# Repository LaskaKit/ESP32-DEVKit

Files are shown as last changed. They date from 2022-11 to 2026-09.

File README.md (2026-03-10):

# ESP32 

DEVkit Are you looking for a combination of a very economical development kit with ESP32 with absolutely simple programming? We have prepared a new development kit just for you, which combines very low power consumption and an integrated programmer. By selecting the right components, the power consumption of the [ESP32-DEVkit](https://www.laskakit.cz/laskakit-esp32-devkit/) in the ESP32's deepest sleep is only 9.5 uA. 

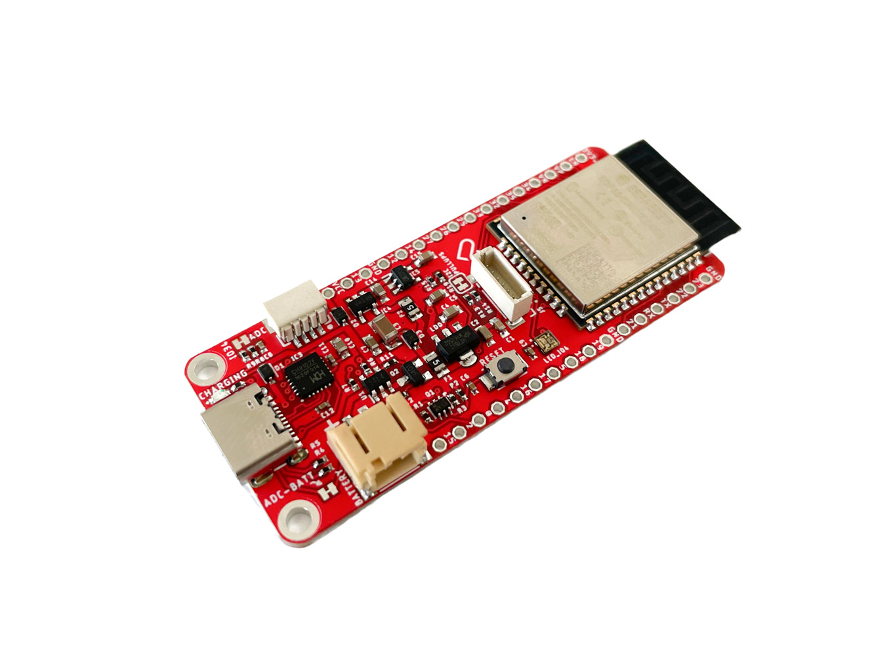
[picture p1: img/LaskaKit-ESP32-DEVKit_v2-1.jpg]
ESP32-DEVkit


As you can see in the picture above, the LaskaKit ESP32 DEVkit comes equipped with a USB-C connector for battery charging and programming, a JST-PH-2 connector for a LiPo/LiIon battery, a user-programmable button, a RESET button, and GPIO headers on each side of the board. 

What we are 100% sure of is that you will like our connector, which we have dubbed "μŠup". 

It's small and durable at the same time and you can't switch the polarity of the sensor by mistake. It's just a safe and reliable method of connecting sensors or I/O devices. With this connector, you can connect the development board to whole host of devices. The connector is pin-compatible with Adafruit Stemma and Sparkfun Qwiik. Some examples of sensors we've designed are: [SHT40 (temperature/humidity)](https://www.laskakit.cz/laskakit-sht40-senzor-teploty-a-vlhkosti-vzduchu/), [BME280 (temperature, humidity, atmospheric pressure)](https://www.laskakit.cz/arduino-senzor-tlaku--teploty-a-vlhkosti-bme280/), [SCD41 (CO2, temperature, humidity)](https://www.laskakit.cz/laskakit-scd41-senzor-co2--teploty-a-vlhkosti-vzduchu/).

The ESP32-DEVkit contains a voltage divider that is connected to the IO34 (a solder bridge on the back of the board must be shorted to enable it). 

## Charging circuitry

Battery charging is enabled by the TP4054 charging circuit, while a stable voltage of 3.3V for the microcontroller is provided by the RT9080-33 low-power voltage stabilizer. The CH9102F USB-UART converter allows easy programming and communication with a computer. 

## Other hardware 

Outside of what we have already mentioned, there is also a user-programmable button, reset button, and RGB LED (SK6812) on the board for signaling or user interface. The pin pitch is designed so that the board can be easily inserted into the solderless contact field, making prototyping and development much easier. 

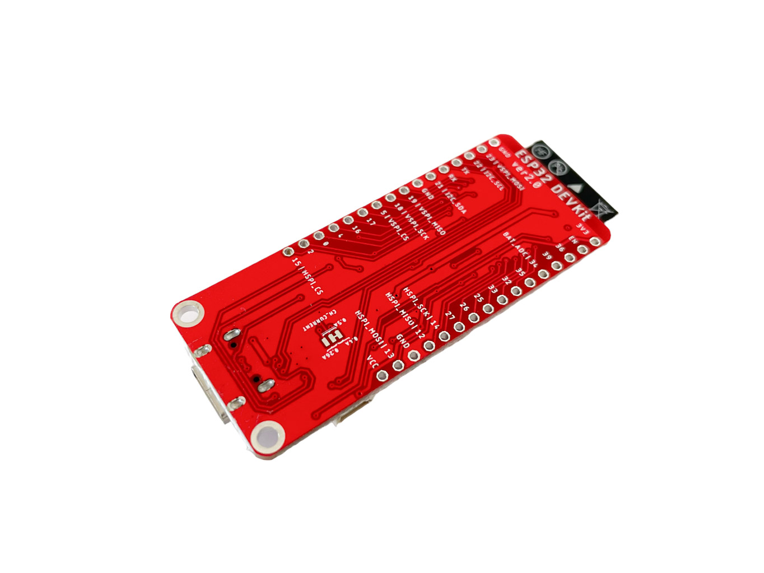
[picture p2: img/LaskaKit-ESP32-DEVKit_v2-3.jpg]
ESP32-DEVkit


## Power consumption 

The power consumption of the ESP32 DevKit during deep-sleep mode is only 12,7 µA (at 4.2V). This means that the entire board, powered only by a Li-ion battery with a programmer, consumes only 12,7 µA.

## Programming
Programming is trivial thanks to the CH9102F programmer. All you have to do is connect a USB-C cable to the board, select the correct port in Arduino IDE, and press "Upload".

Example programs can be found at: https://github.com/LaskaKit/ESP32-DEVKit/tree/main/SW

## Specifications

- Microcontroller: ESP32-WROOM-32 (16 MB Flash)
- Wireless connectivity: Wi-Fi 802.11 b/g/n, Bluetooth
- Power: USB-C, 5V, or 1S LiIon/LiPol battery
- Vin: 3,5–5,5 V
- Battery charging: Integrated TP4054 charging circuit
- Voltage regulators:
  - ESP32:  RT9080
  - Connected devices: RT9080, IO2 -> HIGH to enable
- USB-UART converter: CH9102F
- Deep sleep power consuption: ~12,7 µA (without peripherals)
- Device buses:
  - µŠup I2C: JST-SH 4 pin (SDA: IO21; SCL: IO22)
  - µŠup SPI: JST-SH 6 pin (CS: IO15; MOSI: IO13; SCK: IO14; MISO: IO12)
- LED: SK6812-EC20 (adressable RGB LED at IO4)
- Button: IO17 -> Pressed = LOW
- Battery connector: JST-PH 2-pin
- External antenna connector (IPEX version): IPEX1
- Pin spacing: compatible with solderless breadboards and prototype boards
- Dimensions: 65,5 × 25,5 × 7,5 mm
- Mass: ~9 g

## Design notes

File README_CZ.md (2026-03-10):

# ESP32 DEVkit
Hledáš kombinaci velmi úsporného vývojového kitu s ESP32 s naprosto jednoduchým programováním? Právě pro tebe jsme připravili nový vývojový kit, který práce kombinuje velmi nízkou spotřebu a integrovaný programátor. Díky výběru vhodných součátek je spotřeba [ESP32-DEVkit](https://www.laskakit.cz/laskakit-esp32-devkit/) v nejhlubším spánku ESP32 pouhých 9.5 uA. 

ESP32-DEVkit

Jak můžeš vidět na obrázku výše, vývojový kit ESO32 DEVkit obsahuje USB-C konektor pro nabíjení akumulátoru a programování, konektor pro Lipol akumulátor, uživatelské tlačitko, tlačítko RESET, a GPIO hřebínky po obou stranách desky. 

Co jsme si 100% jistí je, že se ti zalíbí náš konektor, který jsme nazvali μŠup. Je to malý, zároveň odolný a nemůže se ti stát, že bys čidlo přepóloval. Je prostě bezpečný. S tímto konektorem můžeš vývojovou desku připojit k další spoustě čidel a desek. Některé už máme skladem, na jiných pracujeme. Konektor je pinově kompatibilní s Adafruit Stemma a Sparkfun Qwiik.

Například [SHT40 (teplota/vlhkost)](https://www.laskakit.cz/laskakit-sht40-senzor-teploty-a-vlhkosti-vzduchu/), [BME280 (teplota, vlhkost, atmosférický tlak)](https://www.laskakit.cz/arduino-senzor-tlaku--teploty-a-vlhkosti-bme280/), [SCD41 (CO2, teplota, vlhkost)](https://www.laskakit.cz/laskakit-scd41-senzor-co2--teploty-a-vlhkosti-vzduchu/).

ESP32-DEVkit obsahuje dělič napětí, který je připojen k IO34 (je třeba zkratovat pájecí můstek na zadní straně desky).

## Nabíjecí obvod
Nabíjení baterie zajišťuje nabíjecí obvod TP4054, zatímco stabilní napětí 3,3 V pro mikrokontroler poskytuje nízkopříkonový stabilizátor RT9080-33. USB-UART převodník CH9102F umožňuje snadné programování a komunikaci s počítačem. 

## Další hardware
Na desce je také uživatelské tlačítko, reset tlačítko a RGB LED (SK6812) pro signalizaci nebo uživatelské rozhraní. Rozteč pinů je navržena tak, aby bylo možné desku snadno zasunout do nepájivého kontaktního pole, což výrazně usnadňuje prototypování a vývoj.

ESP32-DEVkit

## Spotřeba
Spotřeba ESP32 LP kit během režimu spánku je pouhých 12,7 µA (při 4,2V). To znamená, že celá deska, napájena pouze z Li-ion akumulátoru s osazeným programátorem odebírá pouhých 12,7 µA. 

## Programování
Programování je díky osazenému programátoru velmi jednoduché, připojíš USB-C kabel do desky, v Arduino IDE vybereš port, kam je programátor připojený a tvůj kód nahraješ kliknutím na “Nahrát”.

Vzorový kód nalezneš na https://github.com/LaskaKit/ESP32-DEVKit/tree/main/SW

## Specifikace

- Mikrokontroler: ESP32-WROOM-32 (16 MB Flash)
- Bezdrátová konektivita: Wi-Fi 802.11 b/g/n, Bluetooth
- Napájení: přes USB-C nebo Li-Ion akumulátor (1 článek)
- Napájecí napětí: 3,5–5,5 V
- Nabíjení baterie: integrovaná Li-Ion nabíječka TP4054
- Stabilizátory napětí:
  - ESP:  RT9080
  - Pereferie: RT9080, IO2 -> HIGH pro zapnutí
- USB-UART převodník: CH9102F
- Odběr proudu v deep-sleep režimu: přibližně 12,7 µA (bez připojených periferií)
- Sběrnice senzorů:
  - µŠup I2C: JST-SH 4 pin (SDA: IO21; SCL: IO22)
  - µŠup SPI: JST-SH 6 pin (CS: IO15; MOSI: IO13; SCK: IO14; MISO: IO12)
- LED: SK6812-EC20 (adresovatelná RGB LED na IO4)
- Tlačítko: IO17 -> Stisknuto = LOW
- Konektor pro baterii: JST-PH 2-pin
- Konektor pro externí anténu (u IPEX verze): IPEX1
- Rozteč pinů: kompatibilní s nepájivým kontaktním polem
- Rozměry: 65,5 × 25,5 × 7,5 mm
- Hmotnost: přibližně 9 g

ESP32-DEVkit si můžeš zakoupit na https://www.laskakit.cz/laskakit-esp32-devkit/?variantId=11481

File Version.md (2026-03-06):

### Version 3.0
- All new power part
#### Version 2.0
- New µŠUP SPI connector (need to be powered by pin IO02)
- RGB LED on pin IO04 (need to be powered by pin IO02)
#### Version 1.2
- Separated LDO with Enable pin IO02 for uSup connector, 500mA max on 3.3V
#### Version 1.1
- Přidána propojka na odpojení rezistorového děliče ADC od baterie
#### Version 1.0
- Initial | Počáteční

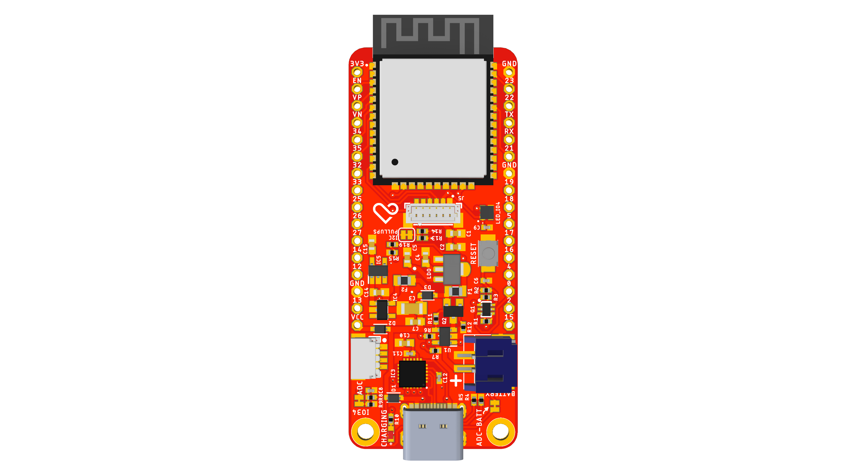
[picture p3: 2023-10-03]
img/ESP32-DEVKit_v2_front.png

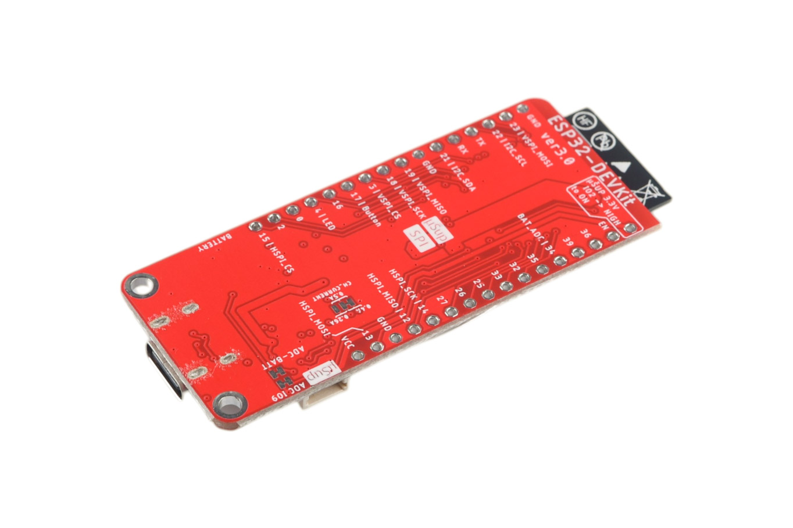
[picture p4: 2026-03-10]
img/LaskaKit-laskakit-esp32-devkit_V3-4.jpg

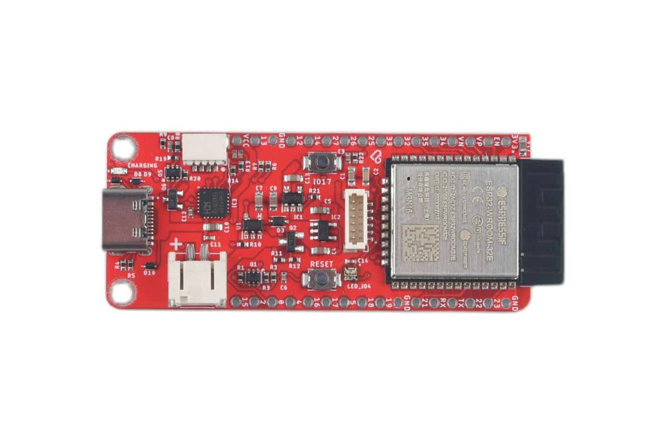
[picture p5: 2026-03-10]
img/LaskaKit-laskakit-esp32-devkit_V3-3.jpg

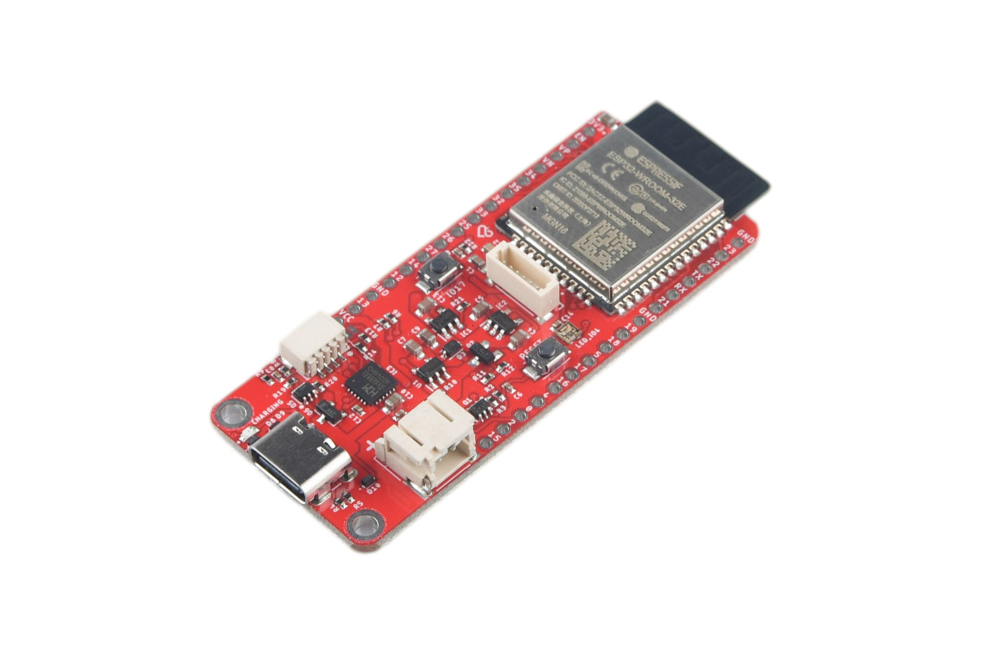
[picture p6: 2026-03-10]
img/LaskaKit-laskakit-esp32-devkit_V3-1.jpg

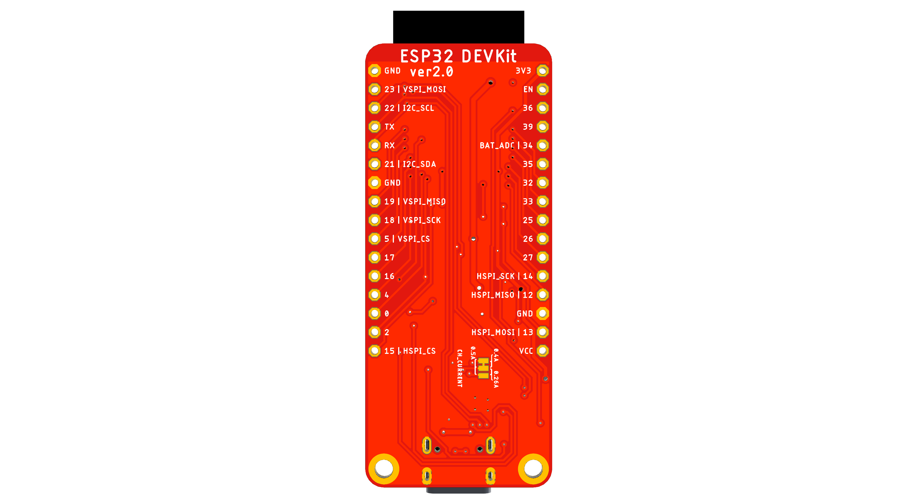
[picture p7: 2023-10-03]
img/ESP32-DEVKit_v2_back.png

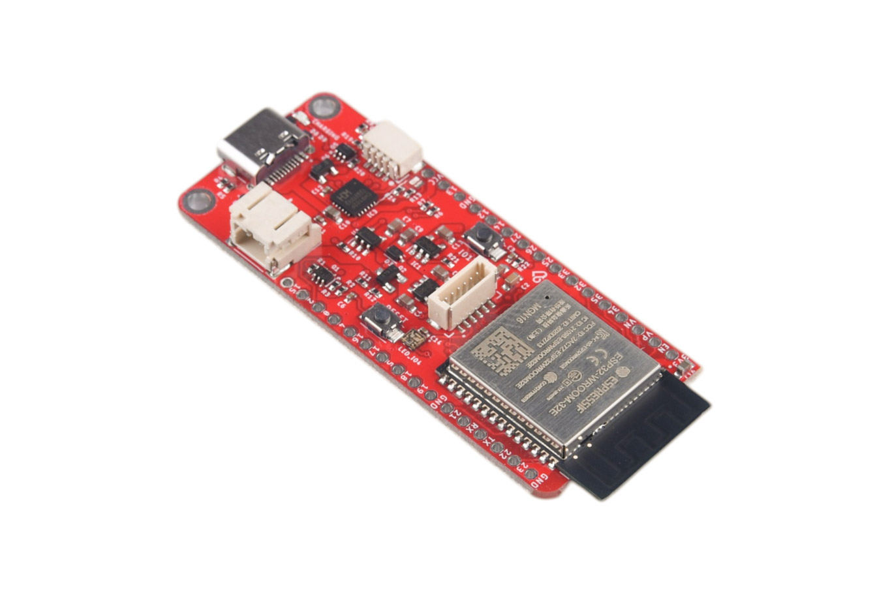
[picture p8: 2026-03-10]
img/LaskaKit-laskakit-esp32-devkit_V3-2.jpg

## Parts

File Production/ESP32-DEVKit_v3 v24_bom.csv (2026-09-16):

Comment | Designator | Footprint | LCSC Part #
1.3M | R9 | R0402
1M | R8 | R0402
1k65 | R6 | R0402
3.3k | R10 | R0402
3k3 | R7 | R0402
4.7k | R13 R14 | R0402
5.1k | R4 R5 | R0402
10k | R1 R2 R3 R11 R21 R22 | R0402
10uF/16V | C4 C5 C7 C9 C13 | C0603
22uF | C10 C16 | C0603
47k | R19 R20 | R0402
47uF | C2 | C0603
100k | R12 | R0402
100n | C11 C12 | C0402
100nF | C1 | C0603
100nF | C3 C6 C8 C14 | C0402
AO3401 | Q2 | SOT23
BAT60B | D3 | SOD323-R
CH9102F | IC3 | QFN24-4X4
DMG2305UX | Q6 | MICRO3 | C144153
EN button | RESET | TS1088R02026 | C455280
ESP32-WROOM-32E | IC4 | ESP32WROOM32E
JST-PH-2_SMD/90SMD | BATTERY | S2B-PH-SM4 | C47647
LESD5D5.0CT1G | D8 D9 D10 | LESD5D50CT1G
MMDT3904 | Q1 | SC70-6 | C268586
MMDT5401 | Q5 | SC70-6 | C54540
RED | CHARGING | CHIP-LED0603 | C2286
RT9080-33GJ5 | IC1 IC2 | SOT94P280X100-5N
SK6812-EC20 | LED_IO4 | SK6812EC20
TP4054 | U1 | SOT-23-5 | C32574
USB-C_GT-USB-7010B | J4 | G-SWITCH_GT-USB-7010B | C2837092
USUP_4P_V | J3 | 1X04_1MM_RA
USUP_SPI_CONNECTOR_VERT | J5 | 1X06_1MM_RA_VERT | C145963
user button | IO17 | TS1088R02026 | C455280

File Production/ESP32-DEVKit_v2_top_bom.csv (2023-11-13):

Comment | Designator | Footprint | LCSC Part #
1.3M | R9 | R0402
1M | R8 R15 | R0402
1k65 | R6 | R0402
1uF | C7 | C0603
3k3 | R7 | R0402
4.7k | R13 R14 | R0402
5.1k | R4 R5 | R0402
10k | R1 R2 R3 R11 R19 | R0402
22uF | C4 C5 C10 C14 C15 | C0603
47uF | C2 | C0603
100k | R12 | R0402
100n | C11 C12 | C0402
100nF | C1 | C0603
100nF | C6 C8 C9 | C0402
100uF | C3 | C1206
330 | R10 | R0402
AO3401 | Q2 | SOT23
AP2191WG-7 | IC4 | SOT25 | C141321
BAT60B | D1 D2 D3 | SOD323-R
CH9102F | IC3 | QFN24-4X4
EN button | RESET | TS1088R02026 | C455280
ESP32-WROOM-32E | IC2 | ESP32WROOM32E
HT7833 | LDO | SOT89-BCE
JST-PH-2/90SMD | BATTERY | S2B-PH-SM4 | C47647
ME6211C33M5G | IC5 | SOT23-5
MMDT3904 | Q1 | SC70-6 | C268586
POLIFUSE0500805L | F1 F2 | 0805L | C66452
RED | CHARGING | CHIP-LED0603 | C2286
SK6812-EC20 | LED_IO4 | SK6812EC20
TP4054 | U1 | SOT-23-5 | C32574
USB-C_2-16PIN | J4 | USBC_USB-C-16P-5 | C2837092
USUP_SPI_CONNECTOR_VERT | J5 | 1X06_1MM_RA_VERT | C145963
JST-SH-4P | J3 | JST-SH-4P | C145956

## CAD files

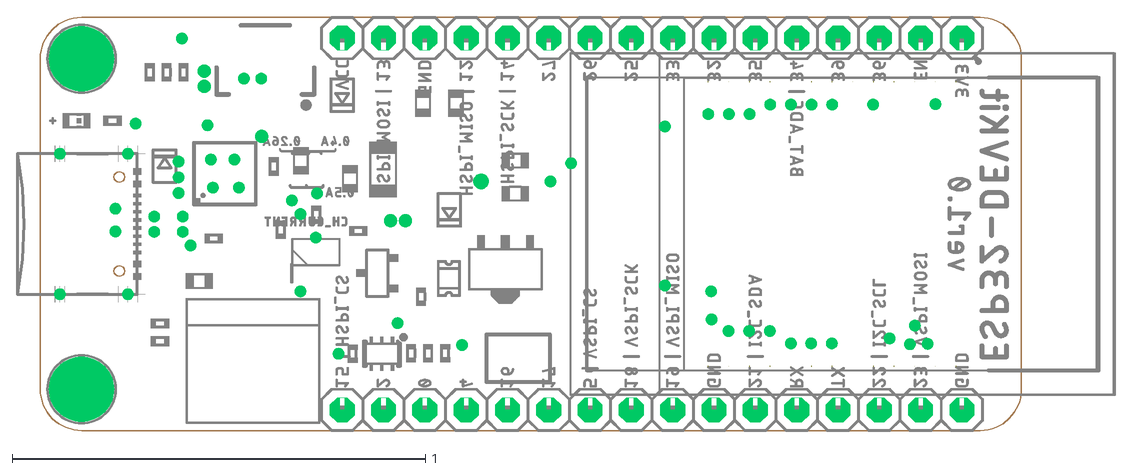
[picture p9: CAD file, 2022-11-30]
HW/ESP32-DEVKit.dxf
2.66 x 1.01

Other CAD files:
3D/ESP32-DEVKit_v3.f3d

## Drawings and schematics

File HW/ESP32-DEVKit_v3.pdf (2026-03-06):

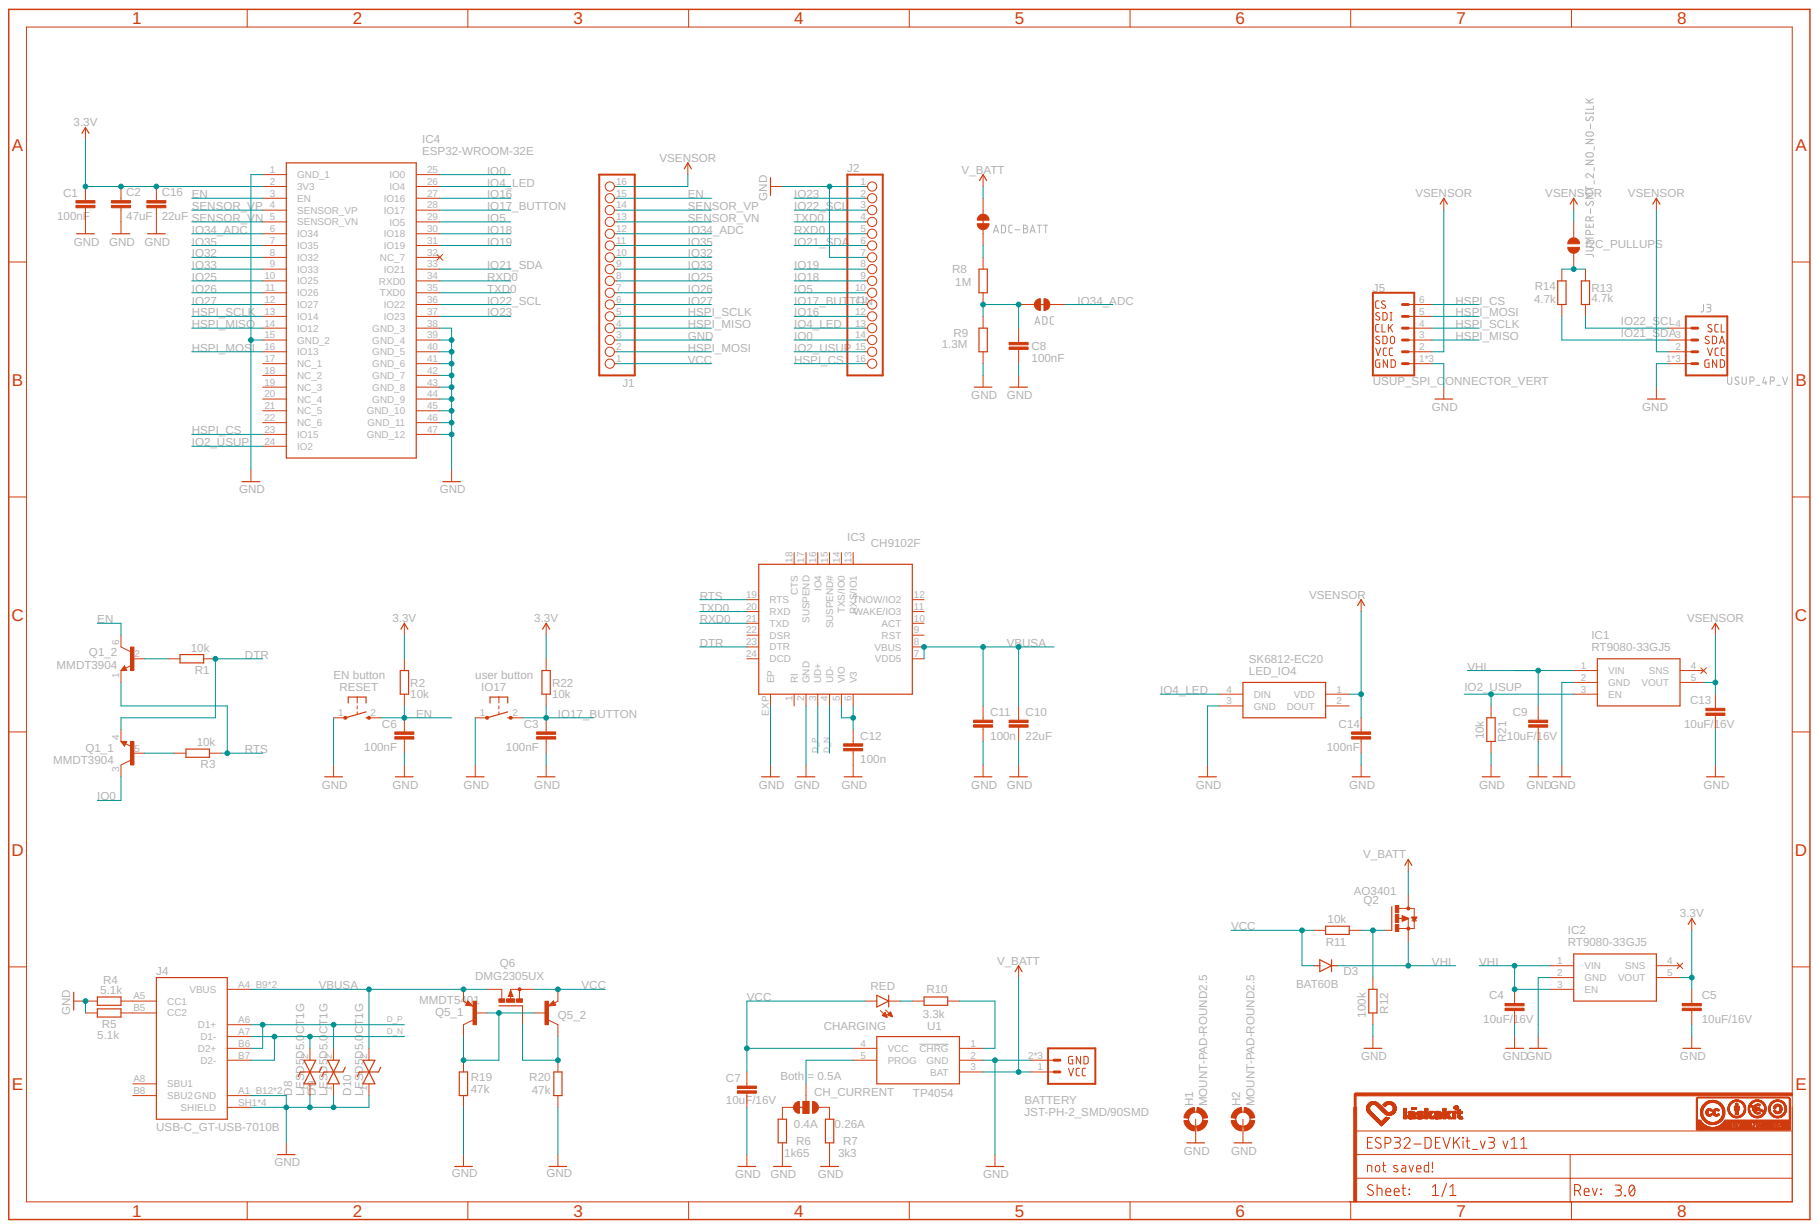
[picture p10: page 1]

MOUNT-PAD-ROUND2.5 MOUNT-PAD-ROUND2.5 GND GND

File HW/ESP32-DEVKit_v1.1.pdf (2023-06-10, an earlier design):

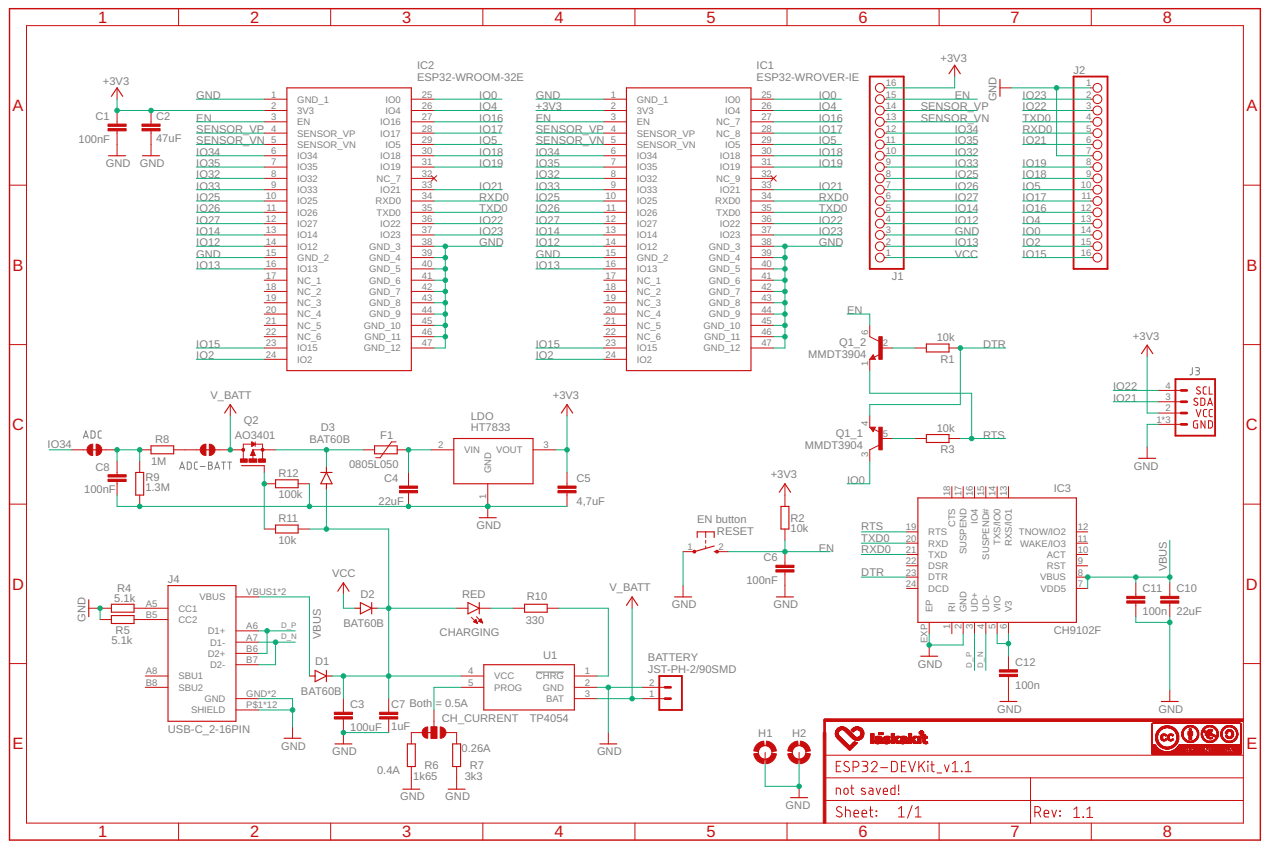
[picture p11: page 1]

40 GND_6 | 40 GND_6
41 GND_7 | | 41 GND_7 | J1
42 GND_8 | 42 GND_8
43 GND_9 | | 43 GND_9
44 GND_10 | 44 GND_10
45 GND_11 | | 45 GND_11

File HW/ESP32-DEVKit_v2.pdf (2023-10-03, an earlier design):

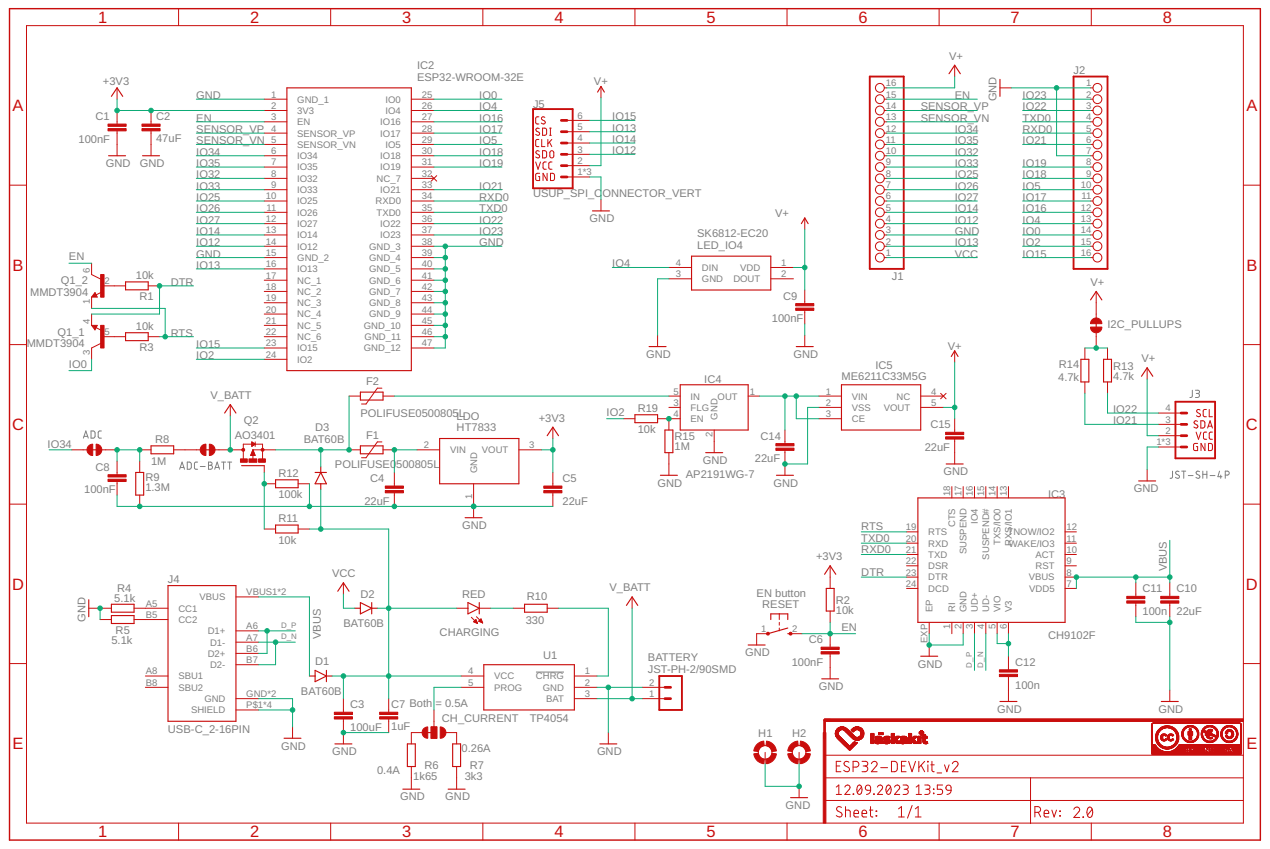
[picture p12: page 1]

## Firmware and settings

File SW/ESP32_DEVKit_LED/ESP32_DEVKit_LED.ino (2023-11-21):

/*
* This example code is used for LaskaKit ESP32-DEVKit board  https://www.laskakit.cz/laskakit-esp32-devkit/
* ESP32-DEVKit just changing LED color 
* 
* Made by (c) laskakit.cz 2023
* 
*/

#include <Adafruit_NeoPixel.h>
#define PIN_ON 02
#define PIN_LED 04

Adafruit_NeoPixel pixels = Adafruit_NeoPixel(1, PIN_LED, NEO_GRB + NEO_KHZ800);

void setup() {
  Serial.begin(115200);
  pinMode(2, OUTPUT);    // Set uSUP connector power transistor as output
  digitalWrite(2, HIGH); // Turn power ON uSUP connector
  delay(100);            // Delay so it has time to turn on

  pixels.begin();
  pixels.setBrightness(10);
}

void loop() {
     
  pixels.setPixelColor(0, pixels.Color(255, 0, 0)); // R, G, B
  pixels.show();

  delay(1000);

  pixels.setPixelColor(0, pixels.Color(0, 255, 0)); // R, G, B
  pixels.show();

  delay(1000);

  pixels.setPixelColor(0, pixels.Color(0, 0, 255)); // R, G, B
  pixels.show();

  delay(1000);

  pixels.setPixelColor(0, pixels.Color(255, 255, 255)); // R, G, B
  pixels.show();

  delay(1000);

}

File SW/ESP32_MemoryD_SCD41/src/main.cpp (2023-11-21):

/*
 * Example code for LaskaKit SCD41 (CO2 sensor) LaskaKit ESP32-lpkit and LaskaKit Memory display
 * 
 * Boards:
 * https://www.laskakit.cz/laskakit-esp32-lpkit-pcb-antenna/
 * https://www.laskakit.cz/laskakit-scd41-senzor-co2--teploty-a-vlhkosti-vzduchu/
 * https://www.laskakit.cz/laskakit-2-7--400x240-lcd-memory-displej/
 * 
 * 
 * Library:
 * https://github.com/sparkfun/SparkFun_SCD4x_Arduino_Library
 * 
 * Made by laskakit.cz (c) 2021
  */

#include <Arduino.h>
#include <Adafruit_GFX.h>
#include <Adafruit_SharpMem.h>
#include <WiFi.h>
#include "SparkFun_SCD4x_Arduino_Library.h"

#include "Orbitron_Bold_24.h"
#include "Orbitron_Bold_42.h"
#include "Orbitron_Bold_72.h"

// SPI uSUP LaskaKit ESP32-DEVKit https://www.laskakit.cz/laskakit-esp32-devkit/
#define SHARP_SCK  14
#define SHARP_MOSI 13
#define SHARP_CS   15

// SPI uSUP LaskaKit ESP32-S3-DEVKit https://www.laskakit.cz/laskakit-esp32-s3-devkit
//#define SHARP_SCK  12
//#define SHARP_MOSI 11
//#define SHARP_CS   10

Adafruit_SharpMem display(SHARP_SCK, SHARP_MOSI, SHARP_CS, 400, 250);


#define BLACK 0
#define WHITE 1
#define uS_TO_S_FACTOR 1000000

SCD4x SCD41;
float ADC_VALUE;
float voltage_value;
uint16_t CO2;
float temperature;
float humidity;

void setup(void) {

  WiFi.mode(WIFI_MODE_NULL);
    
    pinMode(2, OUTPUT);    // Set uSUP connector power transistor as output
  digitalWrite(2, HIGH); // Turn power ON uSUP connector
  delay(100);            // Delay so it has time to turn on

  ADC_VALUE = analogRead(34);

  Serial.begin(9600);
  Wire.begin();

  //             begin, autoCalibrate
  //               |      |
  if (SCD41.begin(false, true) == false) {
    Serial.println("SCD41 was not set correctly. Check the connection.");
    while (1)
      ;
  }

  if (SCD41.startLowPowerPeriodicMeasurement() == true) {
    Serial.println("Low power mode enabled.");
  }

  // start & clear the display
  display.begin();
  display.setRotation(0);
  display.clearDisplay();

}

void loop(void) {

  while (!SCD41.readMeasurement()) {
    delay(100);
  }

  CO2 = SCD41.getCO2();
  temperature =SCD41.getTemperature();
  humidity = SCD41.getHumidity();

  Serial.println();
  Serial.print("CO2(ppm):");
  Serial.print(CO2);
  Serial.print("\tTemperature(C):");
  Serial.print(temperature, 1);
  Serial.print("\tHumidity(%RH):");
  Serial.print(humidity, 1);
  Serial.println();

  display.setTextColor(BLACK, WHITE);
  display.setFont(&Orbitron_Bold_72);

  display.setCursor(10,62);
  display.println(CO2);

  display.setCursor(10,124);
  display.println(temperature);
  
  display.setCursor(10,186);
  display.println(humidity);

  display.setFont(&Orbitron_Bold_42);
  display.setCursor(10,230);
  voltage_value = (float)((ADC_VALUE * 3.3 ) / (4095))*1.560;
  display.println(voltage_value);

  delay(100);
  display.refresh();
  delay(100);
  
  Serial.print("going to sleep");
  esp_sleep_enable_timer_wakeup(300 * uS_TO_S_FACTOR);
  Serial.flush(); 
  esp_deep_sleep_start();

}

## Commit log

2023-02-10 new ver
    [ESP32-DEVKit.dxf, ESP32-DEVKit_top_bom.csv, ESP32-DEVKit_v1.1_bom.csv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]
2023-02-18 data update
    [ESP32-DEVKit_v1.1_bom.csv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]
2023-04-27 new test version
    [ESP32-DEVKit_v1.2_top_bom.csv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]
2023-11-13 old data moved
    [ESP32-DEVKit_v1.1_bom.csv, ESP32-DEVKit_v1.2_top_bom.csv, ESP32-DEVKit_v2_top_bom.csv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]
2025-06-26 Update README.md
    Added a mention of which pin μŠup power is connected to.
2026-03-06 updated to latest ver
    [ESP32-DEVKit_v2_top_bom.csv, ESP32-DEVKit_v3 v21_bom.csv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]
2026-09-16 new data
    [ESP32-DEVKit_v3 v24_bom.csv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]
